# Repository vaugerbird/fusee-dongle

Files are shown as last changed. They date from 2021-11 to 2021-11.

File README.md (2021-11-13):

# HOPEFULLY THIS WARNING IS BIG ENOUGH!
**DO NOT use this repository as it stands!!! I still have much to work on, I just made it public in case there was anybody that wanted to see what I'm doing or help out**

# fusee-dongle
A single PCB fusee injector dongle based around the Atmel SAMD21. Based on my [sam fusee launcher](https://github.com/vaugerbird/sam-fusee-launcher) project, which is based on [sam fusee launcher](https://github.com/noemu/sam-fusee-launcher). This project uses a modified version of main.ino from [electronrancher's SAMD_Fusee_Multiloader](https://github.com/electronrancher/SAMD_Fusee_Multiloader) to allow multiple for payloads.

## Standard disclaimer
This project was created only for educational purposes, and does not enable any kind of copyright infringement. Seriously, don't use this project for anything illegal, I don't need or want the Ninty ninjas coming after me.

# Build and Install
### Create/Update the Payload
* Download your favorite payload(s) from its appropriate repository(s)
* Run the python script in the `tools` folder, using the appropriate converter for your payload, with this command, replacing the path with your own:
`python binConverterPayload.py "C:\pathToMyPayload\payloadName.bin"`, or just drag the .bin file on the script to automatically add the path
* In the same folder as the .bin file is located, a new .h file should appear. Make sure the new file is named `hekate.h`, `fusee.h`, and `package3.h`. Copy the new file to the `main` folder and choose to replace the old file

### Install Board to IDE
* Download and install arduino IDE http://www.arduino.cc/en/Main/Software
* In Arduino: go to "Preferences" and add to "Additional Board Manager URLs" following URL:  `custom board definition coming soon`
* Go to "Tools > Board > Board Manager" and select "Type: All" and
* Input "Fusee Dongle" in the search box
* Install "SAMD Fusee Dongle"
* Select the dongle with "Tools > Board > SAMD Fusee Dongle"

### IDE Setup
* Go to "Sketch > Include Library > Manage Libraries" and install USBHost and FlashStorage
* Connect the dongle to your computer and double click the reset button
* Go to "Tools > Port" and select your connected dongle. (If the name does not show up, use Device Manager to find the proper COM port)
* Download this repository, open main/main.ino with Arduino IDE

### Usage
* When the LED is blinking blue, plug the dongle in and the payload should inject automatically
* To change the payload, press the leftmost button once to advance the payload, and press the rightmost one to confirm the selected payload.
* If you want to inject again, press the middle button and the light should start blinking blue again

Status LED meanings:
* 1 blink blue -> searching for Switch, injecting payload 1
* 2 blinks blue -> searching for Switch, injecting payload 2
* 3 blinks blue -> searching for Switch, injecting payload 3
* Red -> no Switch found
* Solid green, then off (except the power LED) -> finished successfully

# Thanks to:
* [electronrancher](https://github.com/electronrancher)
* [noemu](https://github.com/noemu/sam-fusee-launcher)
* [atlas44](https://github.com/atlas44/sam-fusee-launcher)
* [CTCaer](https://github.com/CTCaer/hekate)
* [SciresM](https://github.com/SciresM)
* And the rest of the community!

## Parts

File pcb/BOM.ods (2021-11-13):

Part Description | Part # | Mouser # | Digikey # | Footprint | $/Unit – Mouser | $/Unit – Digikey | $/Unit – Other | Qty # | Board ID # | Mouser Link | Digikey Link | Other Link
Atmel ARM Microprocessor | ATSAMD21E18A-AFT | 556-ATSAMD21E18A-AFT | ATSAMD21E18A-AFTCT-ND | TQFP-32 | $4.27 | N/A | N/A | 1 | IC1 | Mouser (https://www.mouser.com/ProductDetail/Microchip-Technology-Atmel/ATSAMD21E18A-AFT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) | Digikey (https://www.digikey.com/en/products/detail/microchip-technology/ATSAMD21E18A-AFT/5057223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) | N/A
Battery Charge Controller | MCP73831T-2ACI/OT | 579-MCP73831T-2ACIOT | MCP73831T-2ACI/OTCT-ND | SOT-23 | $0.69 | $0.69 | N/A | 1 | IC2 | Mouser (https://www.mouser.com/ProductDetail/Microchip-Technology/MCP73831T-2ACI-OT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) | Digikey (https://www.digikey.com/en/products/detail/microchip-technology/MCP73831T-2ACI-OT/964301) | N/A
3.3v Voltage Regulator | XC6217A332MR-G | 865-XC6217A332MR-G | 893-1084-1-ND | SOT-25-5 | $0.80 | $0.80 | N/A | 1 | IC3 | Mouser (https://www.mouser.com/ProductDetail/Torex-Semiconductor/XC6217A332MR-G?qs=AsjdqWjXhJ9cceDfQuqemQ%3D%3D) | Digikey (https://www.digikey.com/en/products/detail/torex-semiconductor-ltd/XC6217A332MR-G/2138128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) | N/A
USB-C Male Plug | USB4155-03-C | 640-USB4155-03C | 2073-USB4155-03-CCT-ND | N/A | $1.67 | $1.67 | N/A | 1 | USB1 | Mouser (https://www.mouser.com/ProductDetail/GCT/USB4155-03-C?qs=TuK3vfAjtkW%2F2Iv0quEBsA%3D%3D) | Digikey (https://www.digikey.com/en/products/detail/gct/USB4155-03-C/14305161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) | N/A
USB-C Female Jack | 12401610E4#2A | 523-12401610E4#2A | 12401610E4#2ACT-ND | N/A | $1.72 | $1.72 | N/A | 1 | USB2 | Mouser (https://www.mouser.com/ProductDetail/Amphenol/12401610E42A?qs=sGAEpiMZZMsyYdr3R27aV7VDaPvRJLsz4Ds7mYeH5j4%3D) | Digikey (https://www.digikey.com/en/products/detail/amphenol-icc-commercial-products/12401610E4-2A/5775519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) | N/A
RGB LED | ASMB-MTB1-0B3A2 | 630-ASMB-MTB1-0B3A2 | N/A | N/A | $0.69 | N/A | N/A | 1 | LED1 | Mouser (https://www.mouser.com/ProductDetail/Broadcom-Avago/ASMB-MTB1-0B3A2) | N/A | N/A
Push Button | EVP-BFAC1A000 | 667-EVP-BFAC1A000 | P19749CT-ND | N/A | $0.28 | $0.28 | N/A | 3 | B1, B2, B3, B4 | Mouser (https://www.mouser.com/ProductDetail/Panasonic/EVP-BFAC1A000?qs=OiaALIbqWFSeImjptaxnOQ%3D%3D) | Digikey (https://www.digikey.com/en/products/detail/panasonic-electronic-components/EVP-BFAC1A000/6125108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) | N/A
2kΩ Resistor | ERJ-S06J202V | 667-ERJ-S06J202V | N/A | 0805 | $0.23 | N/A | N/A | 1 | R1 | Mouser (https://www.mouser.com/ProductDetail/Panasonic/ERJ-S06J202V?qs=Zyl8A9hlmJrDyIkXORmWOQ%3D%3D) | N/A | N/A
470Ω Resistor | ERA-6VEB4700V | 667-ERA-6VEB4700V | 10-ERA-6VEB4700VCT-ND | 0805 | $0.70 | $0.59 | N/A | 1 | R2 | Mouser (https://www.mouser.com/ProductDetail/Panasonic/ERA-6VEB4700V) | Digikey (https://www.digikey.com/en/products/detail/panasonic-electronic-components/ERA-6VEB4700V/12084673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) | N/A
5.1kΩ Resistor | ERJ-T06J512V | 667-ERJ-T06J512V | N/A | 0805 | $0.21 | N/A | N/A | 1 | R3 | Mouser (https://www.mouser.com/ProductDetail/Panasonic/ERJ-T06J512V?qs=iIVTEDlrHA3jjpvS%2FCMhsg%3D%3D) | N/A | N/A
4.7µ Capacitor | CL03A475MQ5C65C | 187-CL03A475MQ5C65C | N/A | 0805 | $0.38 | N/A | N/A | 1 | C1 | Mouser (https://www.mouser.com/ProductDetail/Samsung-Electro-Mechanics/CL03A475MQ5C65C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) | N/A | N/A
2-pin JST-PH Connector | S2B-PH-SM4-TB | N/A | 455-1749-1-ND | N/A | N/A | $0.53 | $0.75 | 1 | JST | N/A | Digikey (https://www.digikey.com/en/products/detail/jst-sales-america-inc/S2B-PH-SM4-TB-LF-SN/926655) | Adafruit (https://www.adafruit.com/product/1769)
1200mAh Li-po | 258 | N/A | 1528-1838-ND | N/A | N/A | $9.95 | $9.95 | 1 | BAT | N/A | Digikey (https://www.digikey.com/en/products/detail/adafruit-industries-llc/258/5054544) | Adafruit (https://www.adafruit.com/product/258)

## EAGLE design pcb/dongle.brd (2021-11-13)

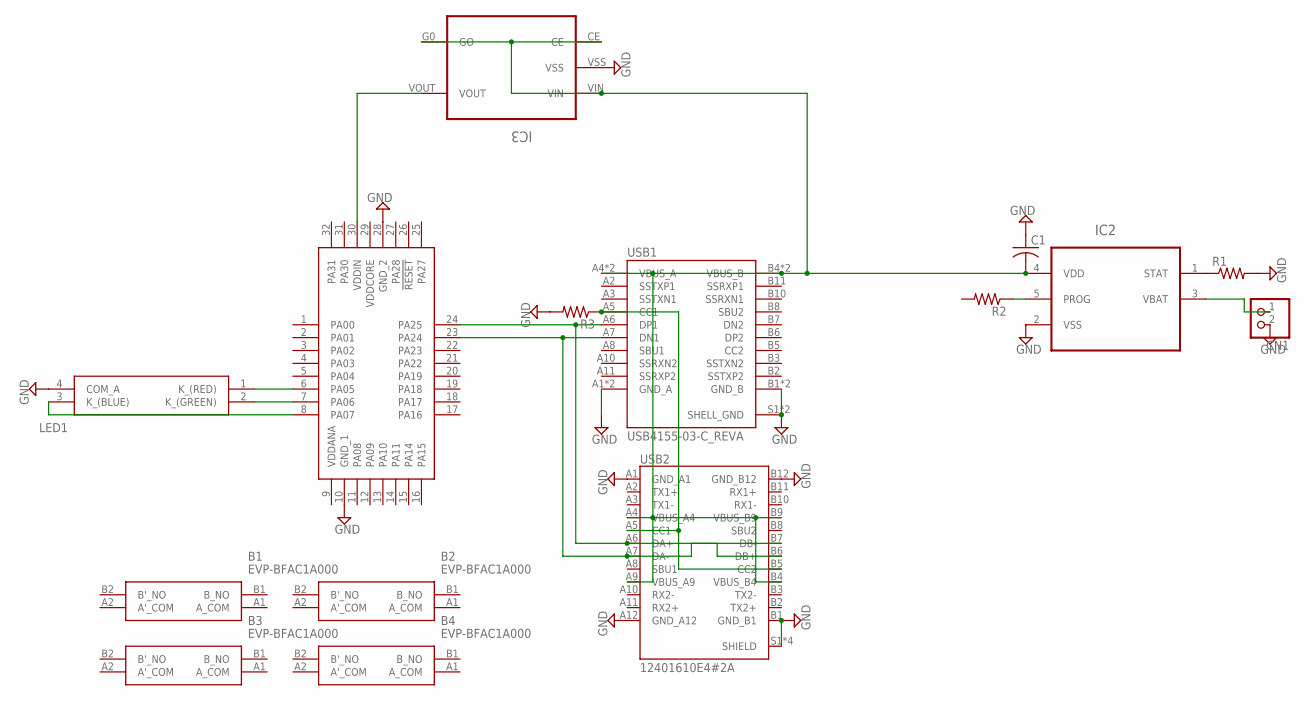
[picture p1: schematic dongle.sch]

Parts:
B1, B2, B3, B4: EVP-BFAC1A000; EVPBFAC1A000
C1: C-USC0805; C0805
CN1: JST_2PIN-SMT-RA; JST-PH-2-SMT-RA
IC1: ATSAMD21E18A-AFT; QFP80P900X900X120-32N
IC2: MCP73831T-2ACI/OT; SOT95P280X145-5N
IC3: IC_XC8107AC20MR-G
LED1: ASMB-MTB1-0B3A2; ASMBMTB10B3A2
R1, R2, R3: R-US_R0805; R0805
USB1: USB4155-03-C_REVA; GCT_USB4155-03-C_REVA
USB2: 12401610E4#2A; AMPHENOL_12401610E4#2A

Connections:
3.3V: IC1.30 (VDDIN), IC3.VOUT
3.3VBAT: CN1.1 (2), IC2.3 (VBAT)
5VIN: C1.2, IC2.4 (VDD), IC3.CE, IC3.G0 (GO), IC3.VIN, USB1.A4 (VBUS_A), USB1.A9 (VBUS_A), USB1.B4 (VBUS_B), USB1.B9 (VBUS_B), USB2.A4 (VBUS_A4), USB2.A9 (VBUS_A9), USB2.B4 (VBUS_B4), USB2.B9 (VBUS_B9)
B: IC1.8 (PA07), LED1.3 (K_(BLUE))
CC: R3.1, USB1.A5 (CC1), USB2.A5 (CC1), USB2.B5 (CC2)
D+: IC1.24 (PA25), USB1.A6 (DP1), USB2.A6 (DA+), USB2.B6 (DB+)
D-: IC1.23 (PA24), USB1.A7 (DN1), USB2.A7 (DA-), USB2.B7 (DB-)
G: IC1.7 (PA06), LED1.2 (K_(GREEN))
GND: C1.1, CN1.2 (1), IC1.10 (GND_1), IC1.28 (GND_2), IC2.2 (VSS), IC3.VSS, LED1.4 (COM_A), R1.2, R3.2, USB1.A1 (GND_A), USB1.A12 (GND_A), USB1.B1 (GND_B), USB1.B12 (GND_B), USB1.S1 (SHELL_GND), USB1.S2 (SHELL_GND), USB2.A1 (GND_A1), USB2.A12 (GND_A12), USB2.B1 (GND_B1), USB2.B12 (GND_B12), USB2.S1 (SHIELD), USB2.S2 (SHIELD), USB2.S3 (SHIELD), USB2.S4 (SHIELD)
PROG: IC2.5 (PROG), R2.1
R: IC1.6 (PA05), LED1.1 (K_(RED))
STAT: IC2.1 (STAT), R1.1

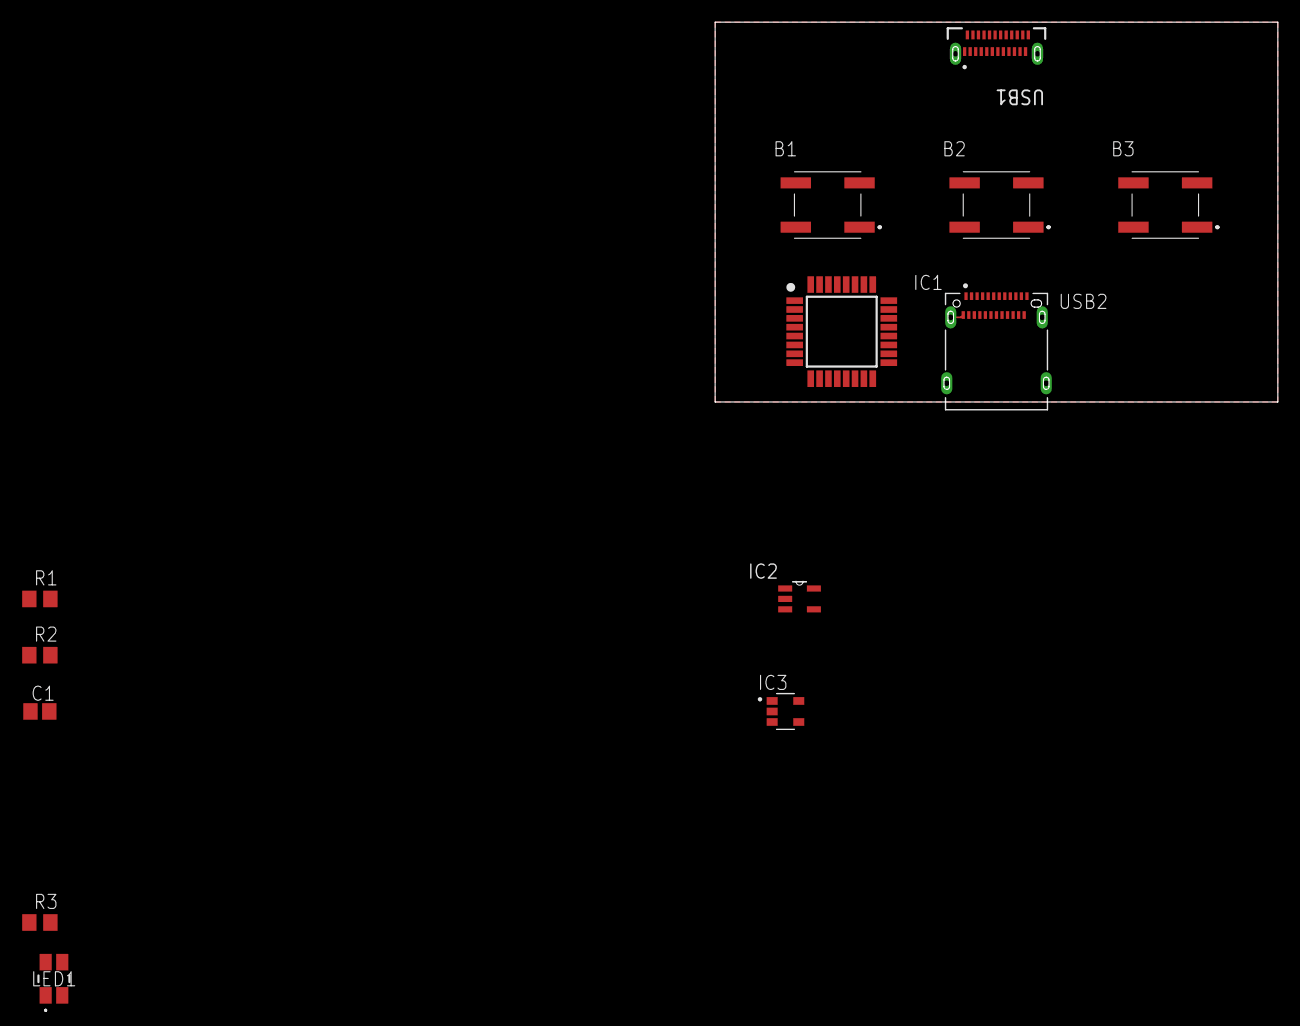
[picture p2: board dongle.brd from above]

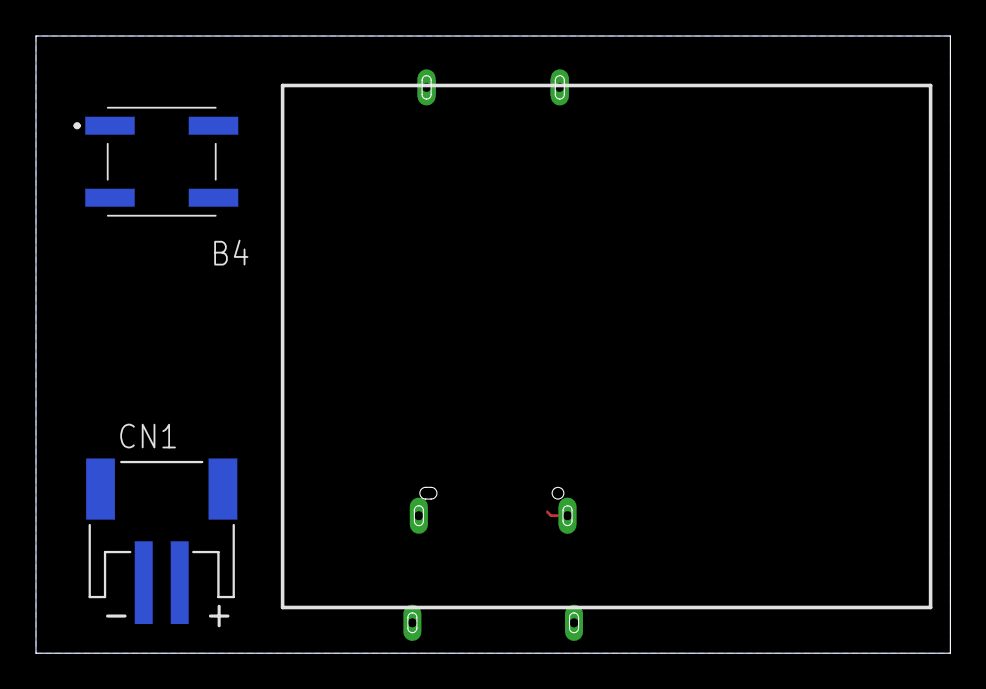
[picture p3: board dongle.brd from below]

Board: 2 copper layers, 50.8 x 34.3 mm, 15 parts (2 on the bottom side), 12 nets.

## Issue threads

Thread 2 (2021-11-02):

Add payload selection

vaugerbird, 2021-11-02:
At some point, I'd like to add the ability to select a payload, with the payloads stored on the SD card inside the Tegra device. I have some ideas on how to do this, but I don't know how to put them into code. My best idea is to inject a version of Hekate that will automatically chainload the selected payload, but that may not work. If I can't read off of the internal SD card, then I may have include a SD card slot on the dongle itself, and that will hold the payloads.

vaugerbird, 2021-11-04:
Now using the main.ino from [SAMD_Fusee_Multiloader](https://github.com/electronrancher/SAMD_Fusee_Multiloader)

Closed 2021-11-04.

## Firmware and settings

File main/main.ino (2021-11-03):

// Multiloader firmware for SAMD Loader - user can now select from 3 payloads
// 1 - hekate
// 2 - fusee.bin
// 3 - package3(?)
//
// On powerup, the board will blink the blue activity LED 1, 2, or 3 times to indicate active payload
//
// To change payload - hold the change button (D1), the device will cycle through 1, 2, then 3 blinks to
// indicate payload selection.  Let go of change button once your desired payload is indicated
//
// To store payload, momentarily press the store button (D0). The activity LED will light for 1 second to indicate flashing
// and upon the next reset, your desired payload will be automatically selected.
//
// The rest is the same, device will blink 1-3 times while searching for Tegra, then give a short-long "Ta-daa" blink
// as the payload is sent and activated.  At that point, you're done!  Unplug and switch the loader off.


#include <FlashAsEEPROM.h>
#include <FlashStorage.h>
#include <Usb.h>
#include <Arduino.h>
#include "fuseegelee.h"
#include "led.h"

// Select bin file payload here
// Must contain bin file as fuseeBin array with correct FUSEE_BIN_SIZE
#include "hekate.h"
#include "fusee.h"
#include "package3.h"

// Pin definition
// Onboard activity LED (blue) - 13
// Change payload button - 1
// Store payload config - 0
#define change 1
#define store 0


FlashStorage(payload_cfg, int);
int payload;     // Get payload config from flash
int gotTegra=0;

void setup()
{
  pinMode(1, OUTPUT);
  pinMode(2, OUTPUT);
  pinMode(3, OUTPUT);
  pinMode(4, OUTPUT);
  pinMode(change, INPUT_PULLUP);
  pinMode(store, INPUT_PULLUP);
  payload = payload_cfg.read();     // Get payload config from flash
  payload%=3;                     // Snap it to 0-2 range
  gotTegra=0;
  // Try to bring up USB
  if (usbInit() == -1){
      setLedColor(red, 255);   // LED on full time means usb Init failed
      SCB->SCR |= SCB_SCR_SLEEPDEEP_Msk; /* Enable deepsleep */
      __DSB(); /* Ensure effect of last store takes effect */
      __WFI(); /* Enter sleep mode */
  }
  
  // OK, USB is up.  Start searching for a Tegra.
  // Search for the Tegra.  Show 1-3 blinks, then pause and repeat
  gotTegra=searchTegraDevice();
  while (!gotTegra)
  {
    if (digitalRead(change)==LOW) ++payload%=3;  //If the change button is pressed, advance the payload
    if (digitalRead(store)==LOW) {
      payload_cfg.write(payload);  //If the store button is pressed, flash payload cfg
      setLedColor(blue, 100);
      delay(1200); //20ms on
      setLedColor(black, 0);
      delay(200);
    }
    for(int i=0; i<=payload; i++){
      setLedColor(blue, 100);
      delay(25); 
      setLedColor(black, 0);
      delay(175);
    }
    gotTegra=searchTegraDevice();
    delay(400); //180ms off
    
  }
  // Found a tegra, let's party
  // There is a delay here when Tegra wakes, the fast blinking stops for a moment
  // Next, you will see short/long LED blink (ta daa!) on the LED as the payload is sent and launched 
  digitalWrite(led, HIGH);                  // Short blink when starting the party (ta)
  delay(20);

  setupTegraDevice();                       // Do USB setup for fusee gelee 

  setLedColor(black, 0);                  // LED Off when sending 
  // Send the selected Payload
  if (payload==2)
    sendPayload(pkgBin, PKG_BIN_SIZE);   
  else if (payload==1)
    sendPayload(atmosBin, ATMOS_BIN_SIZE);  
  else 
    sendPayload(hekateBin, HEKATE_BIN_SIZE);
  setLedColor(blue, 100);                 // On for a medium flash when launching (daa!)

  launchPayload();                          // Launch bin file

  // Turn off LED and go into deep sleep
  sleepDeep(1);
}

void loop()
{
}

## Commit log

2021-11-02 Add starting files
    [BOM.ods, dongle.brd, dongle.sch]
2021-11-03 Lots of all around work on the code and board
    [BOM.ods, dongle.sch]
2021-11-13 Changed some parts sources and worked on board
    [BOM.ods, dongle.brd, dongle.sch]
